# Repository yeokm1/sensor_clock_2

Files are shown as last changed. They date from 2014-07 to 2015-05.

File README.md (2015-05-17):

sensor_clock_2
==============

A clock composed of an Arduino, temperature and humidity sensors. A light-dependent resistor (LDR) is included to dynamically switch on/off the backlight depending on the surrounding light conditions. Includes integrated charger. Simpler than the  [previous sensor-clock](https://github.com/yeokm1/sensor-clock).

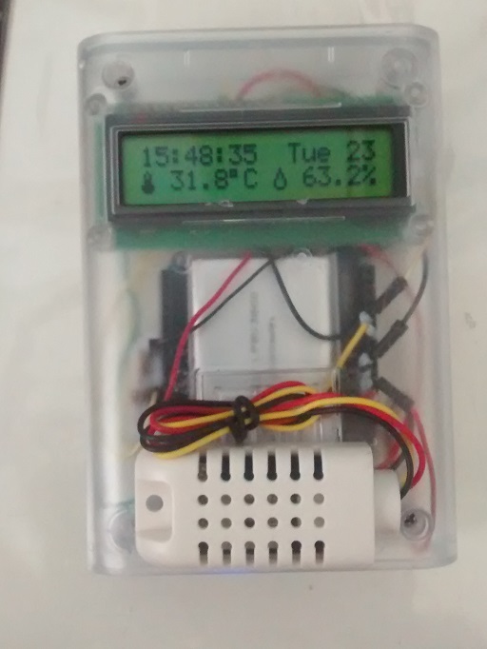
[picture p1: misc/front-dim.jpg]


The white AM2302 temperature/humidity sensor is placed externally to prevent heat from the Arduino from affecting the measurement.

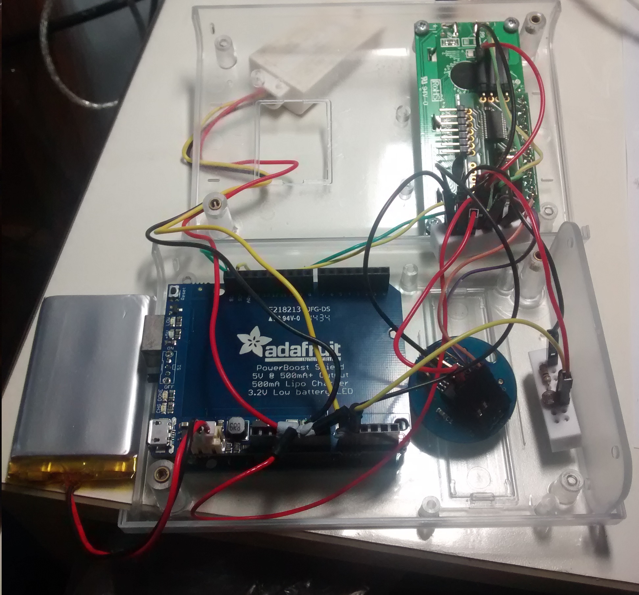
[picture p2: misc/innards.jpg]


Innards.

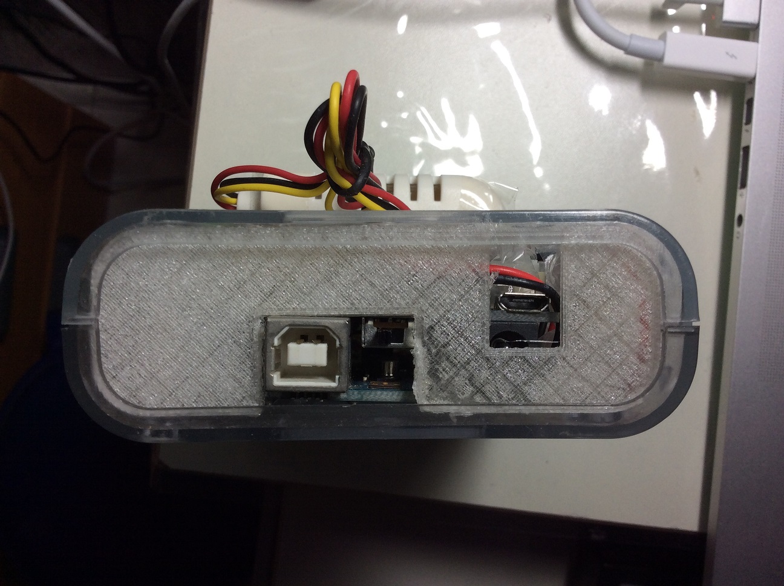
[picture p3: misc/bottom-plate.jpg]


Because of the extra charging connector, I cannot use the default plastic case that came with the case. This base is designed and 3D-printed by me. The Designspark Mechanical and STL files are also in this repo.

<b>Main Parts used:</b>  

1. Arduino UNO R3  (An Uno or other boards will work too)  
2. I2C LCD based on LCD03  
3. AM2302 temperature and humidity sensor  (wired DHT22)
4. Chronodot v2.1 Real Time Clock (Based on DS3231 temperature compensated RTC crystal. Temperature sensor unused)
5. Adafruit PowerBoost 500 Shield
6. Light-dependent Resistor (LDR)
7. 1x 10k ohm resistor for LDR
8. 2x Mini Solderless breadboard - 2x8 points

Optional:  

1. 2000 mAh Lithium battery  
2. Translucent case  
3. Micro-USB cable  

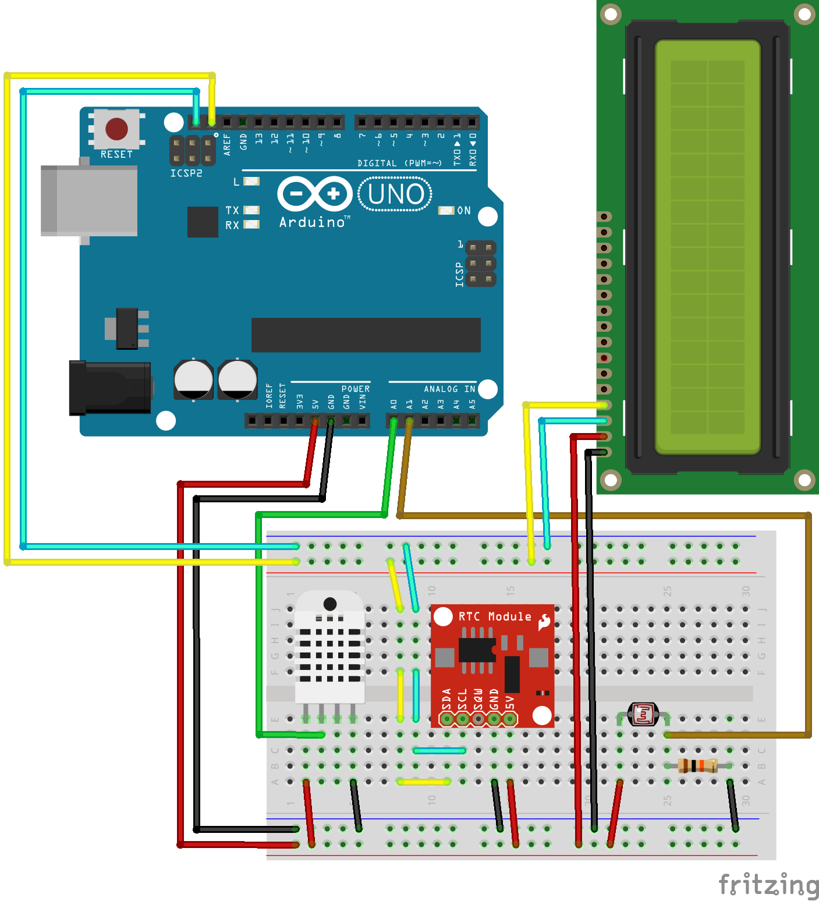
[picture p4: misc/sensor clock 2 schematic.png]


A Fritzing schematic. This schematic only represents the logical connections I made. The physical connections differs due to space issues. As Fritzing does not have DHT22, DS3231 chronodot and I2C LCD, I modified some existing and downloaded designs. Code assumes solder jumper on Powerboost Shield is soldered on pin A3.

<b>Things to take note before modifying my code/design:</b>  

1. AM2302 sensor needs at least 2 seconds delay between readings.  

2. One is supposed to add a pull-up resistor for the I2C bus lines SCL and SDA if more than one device (I2C LCD and Chronodot) uses them. I tried without the resistor and it seems to work fine.

3. Auto power off of lcd and sensors at set times. Can disable by setting TURN_OFF_AT_TIMES to false.

References and libraries:  

1. Get day of week from date.  
(http://stackoverflow.com/a/21235587)

2. Temperature and Humidity Icons  
(http://www.instructables.com/id/Clock-with-termometer-using-Arduino-i2c-16x2-lcd-D/)  

3. Adafruit DHT sensor library
(https://github.com/adafruit/DHT-sensor-library)

4. AnyRTC RTClib  
(https://github.com/maniacbug/AnyRtc)

5. Ports library from jeelibs to save power during delay  
(https://github.com/jcw/jeelib)

6. LCD03 library  
(https://github.com/andatche/arduino-lcd03)

The MIT License (MIT)<br>
Copyright (c) 2014-2014 Yeo Kheng Meng<br>

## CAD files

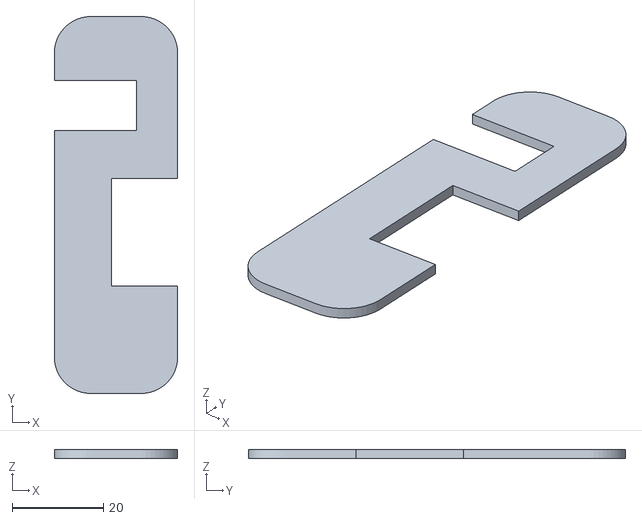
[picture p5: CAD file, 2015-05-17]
misc/bottom plate.stl
27.0 x 82.5 x 1.90

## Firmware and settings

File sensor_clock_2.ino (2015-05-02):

#include <SPI.h>
#include <Wire.h>
#include <JeeLib.h>

#include <DHT.h>
#include <RTC_DS1307.h>

#include <LCD03.h>

#define BATT_PIN A3

#define LED_13_PIN 13

#define LDR_PIN A1

#define DHTPIN A0
#define DHTTYPE DHT22

#define LCD_CHAR_LENGTH 16

#define LCD_DEGREES_SYMBOL (char) 223

#define REFRESH_INTERVAL 5 //Minimum 5 seconds for DHT22 to refresh. Do not exceed 59


#define SLEEP_INTERVAL 250 //0.25s
#define SLEEP_LONG_INTERVAL 45000 //45s

//Slight difference in values to prevent hysteresis effect on the output, constantly turning on and off the LCD
#define LIGHT_THRESHOLD_OFF 55 //Turn off when higher than this
#define LIGHT_THRESHOLD_ON 45 //Turn on when lower than this


#define BATT_MILLIVOLT_NOT_TURN_ON_LIGHT_THRESHOLD 3500

#define OFF_HOUR 00
#define OFF_MIN 00

#define ON_HOUR 07 //Must be bigger than OFF_HOUR
#define ON_MIN 00

#define TURN_OFF_AT_TIMES true  //Set to false if you don't want the screen and readings to stop at certain times.

#define THERM_ICON_REP 1
#define HUM_ICON_REP 2

//Icons from http://www.instructables.com/id/Clock-with-termometer-using-Arduino-i2c-16x2-lcd-D/
byte thermIcon[8] = //icon for thermometer
{
  B00100,
  B01010,
  B01010,
  B01110,
  B01110,
  B11111,
  B11111,
  B01110
};

byte humIcon[8] = //icon for humidity
{
  B00100,
  B00100,
  B01010,
  B01010,
  B10001,
  B10001,
  B10001,
  B01110,
};


DHT dht(DHTPIN, DHTTYPE);
RTC_DS1307 RTC;  //Code for this works although I use DS3231. For the initial time setting convenience.
ISR(WDT_vect) {
  Sleepy::watchdogEvent();  // Setup for low power waiting
}
// Create new LCD03 instance
LCD03 lcd;

int prevIntervalReadingSecond = 0;
int prevUpdateTimeSecond = 0;
int prevUpdateTurnOnAndOffMinute = 0;

bool currentlyOn = true;

bool isLcdBacklightOn = false;

void setup() {
  Serial.begin(9600);

  //Disable LED Pin 13 (Optional). I just hate the constant LED light.
  pinMode(LED_13_PIN, OUTPUT);
  digitalWrite(LED_13_PIN, LOW);

  //Start RTC
  Wire.begin();
  RTC.begin();

  if (!RTC.isrunning()) {
    Serial.println("RTC is NOT running");
  }

  // This section grabs the current datetime and compares it to
  // the compilation time.  If necessary, the RTC is updated.
  DateTime now = RTC.now();
  DateTime compiled = DateTime(__DATE__, __TIME__);

  if (now.unixtime() < compiled.unixtime()) {
    Serial.println("RTC is older than compile time! Updating");
    RTC.adjust(DateTime(__DATE__, __TIME__));
  }

  //Start LCD
  lcd.begin(LCD_CHAR_LENGTH, 2);


  lcd.createChar(THERM_ICON_REP, thermIcon);
  lcd.createChar(HUM_ICON_REP, humIcon);

  changeBacklightStatus(false);

  printThisOnLCDLine("By: YKM", 1);


  //Start DTT
  dht.begin();


}

void loop() {
  DateTime now = RTC.now();


  int second = now.second();
  int minute = now.minute();
  int hour = now.hour();

  int lightValue = analogRead(LDR_PIN);
  Serial.println("LDR");
  Serial.println(lightValue);

  if (currentlyOn) {

    //Update time only if second changes. Prevent needless requests to LCD
    if (second != prevUpdateTimeSecond) {
      prevUpdateTimeSecond = second;
      String dateString = generateDateTimeString(now.year(), now.month(), now.day(), now.hour(), now.minute(), now.second());
      printThisOnLCDLine(dateString, 0);



      if (lightValue < LIGHT_THRESHOLD_ON && !isLcdBacklightOn) {
        int battMilliVolt = getBatteryMilliVoltage();

        if (battMilliVolt > BATT_MILLIVOLT_NOT_TURN_ON_LIGHT_THRESHOLD) {
          changeBacklightStatus(true);
          isLcdBacklightOn = true;
        }

      }

      if (lightValue > LIGHT_THRESHOLD_OFF && isLcdBacklightOn) {
        changeBacklightStatus(false);
        isLcdBacklightOn = false;
      }
    }

    //Every refresh interval
    if ((second % REFRESH_INTERVAL) == 0 && second != prevIntervalReadingSecond) {
      //Prevent multiple readings every interval
      prevIntervalReadingSecond = second;
      Serial.println();
      Serial.print("Take DHT22 Readings: ");


      float DHTTemp = dht.readTemperature();
      float DHTHum = dht.readHumidity();


      Serial.print(DHTHum);
      Serial.print("\t");
      Serial.println(DHTTemp);





      generateAndPrintTempHumString(DHTTemp, DHTHum);




    }
  }




  //Prevent too many execution since only need to check once a minute
  if (TURN_OFF_AT_TIMES && prevUpdateTurnOnAndOffMinute != minute) {
    prevUpdateTurnOnAndOffMinute = minute;

    Serial.println("Checking time");
    if (currentlyOn) {

      if (((hour == OFF_HOUR && minute >= OFF_MIN)
           || (hour > OFF_HOUR && hour < ON_HOUR)) //Exceeded OFF time. The moment display turns on to indicate lights out, go to sleep.
          && isLcdBacklightOn) { //Don't enter sleep mode if background is still bright enough

        currentlyOn = false;
        lcd.clear();
        changeBacklightStatus(false);
        isLcdBacklightOn = false;
        longSleep();
      }

    } else {

      if ((lightValue > LIGHT_THRESHOLD_OFF) //If background bright enough during off hour, turns thing back on
          || (hour == ON_HOUR && minute == ON_MIN)) {
        currentlyOn = true;
      } else {
        longSleep();
      }

    }
  }


  shortSleep();
  //delay(250);

}

void changeBacklightStatus(bool on) {
  if (on) {
    lcd.backlight();
  } else {
    lcd.noBacklight();
  }


}

void shortSleep() {
  Sleepy::loseSomeTime(SLEEP_INTERVAL);

}


void longSleep() {
  Sleepy::loseSomeTime(SLEEP_LONG_INTERVAL);
}

int getBatteryMilliVoltage() {
  int battValue = analogRead(BATT_PIN);
  int battMilliVoltage = (((float) battValue) / 1024) * 5000;
  Serial.print("Batt: ");
  Serial.println(battMilliVoltage);

  return battMilliVoltage;

}


void generateAndPrintTempHumString(float temp, float hum) {

  String tempString = ftoa(temp, 1);
  String humString = ftoa(hum, 1);

  String intermediate1 = " " + tempString + LCD_DEGREES_SYMBOL + "C ";
  String intermediate2 = " " + humString + "%";

  lcd.setCursor (0, 1);
  lcd.write((byte) THERM_ICON_REP);
  lcd.print(intermediate1);
  lcd.write((byte) HUM_ICON_REP);
  lcd.print(intermediate2);

}


String generateTempHumString(float temp, float hum) {
  String tempString = ftoa(temp, 1);
  String humString = ftoa(hum, 1);
  String result = "P:" + tempString + LCD_DEGREES_SYMBOL + "C H:" + humString + "%";
  return result;

}


//Convert float/double to String as ardiuno sprintf does not support float/double
String ftoa(double f, int precision)
{
  long p[] = {0, 10, 100, 1000, 10000, 100000, 1000000, 10000000, 100000000};

  char temp[5];
  char * a = temp;
  long heiltal = (long)f;
  itoa(heiltal, a, 10);
  while (*a != '\0') a++;
  *a++ = '.';
  long desimal = abs((long)((f - heiltal) * p[precision]));
  itoa(desimal, a, 10);
  String result = temp;
  return result;
}

void printThisOnLCDLine(String text, int line) {

  //Clear current line only if the new line cannot occupy the old line
  if (text.length() < LCD_CHAR_LENGTH) {
    lcd.setCursor (0, line);
    lcd.print("                ");
  }

  lcd.setCursor (0, line);
  lcd.print(text);
}

String generateDateTimeString(int year, int month, int day, int hour, int minute, int second) {
  char buff[3];

  sprintf(buff, "%02d", hour);
  String hourString = buff;

  sprintf(buff, "%02d", minute);
  String minuteString = buff;

  sprintf(buff, "%02d", second);
  String secondString = buff;

  String result = hourString + ":" + minuteString + ":" + secondString + " ";

  String dayOfWeek = getDayOfTheWeek(year, month, day);

  sprintf(buff, "%02d", day);
  String dayString = buff;

  String monthString = getMonth(month);

  if (0 <= second && second <= 40) {
    result += " " + dayOfWeek + " " + dayString;
  } else {
    result += monthString + year;
  }
  return result;
}



// From http://stackoverflow.com/a/21235587
String getDayOfTheWeek(int y, int m, int d) {
  String weekdayname[] = {"Sun", "Mon", "Tue",
                          "Wed", "Thu", "Fri", "Sat"
                         };

  int weekday = (d += m < 3 ? y-- : y - 2, 23 * m / 9 + d + 4 + y / 4 - y / 100 + y / 400) % 7;


  return weekdayname[weekday];
}

String getMonth(int month) {
  switch (month) {
    case 1: return "Jan";
    case 2: return "Feb";
    case 3: return "Mar";

    case 4: return "Apr";
    case 5: return "May";
    case 6: return "Jun";

    case 7: return "Jul";
    case 8: return "Aug";
    case 9: return "Sep";

    case 10: return "Oct";
    case 11: return "Nov";
    case 12: return "Dec";
    default : return "Nil";
  }

}

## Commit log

2014-07-02 misc stuff
    [sensor clock 2.fzz]
2014-07-02 picture change
    [sensor clock 2.fzz]
2014-07-03 ldr schemetic
    [sensor clock 2.fzz]
2014-07-25 power wire to DHT22
    [sensor clock 2.fzz]
2014-09-23 turn on backlight only when battery is above threshold
2015-05-02 prevent constant turning on and off backlight when near threshold
    [sensor_clock_2.ino]
2015-05-17 bottom plate 3D files
    [bottom plate.stl]
2015-05-17 bottom plate
